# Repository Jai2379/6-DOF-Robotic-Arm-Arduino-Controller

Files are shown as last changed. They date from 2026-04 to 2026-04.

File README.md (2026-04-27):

# 6-DOF Robotic Arm — Arduino Controller

A fully articulated 6-degree-of-freedom robotic arm designed from scratch in SolidWorks and driven by an Arduino-based servo control system. The mechanical design mirrors real industrial robotics architectures — parallel linkages, modular joints, and a kinematic chain built for precision.

---

## Overview

Six degrees of freedom — the same mobility as a human arm. This project spans the full engineering pipeline: mechanical design in SolidWorks, kinematic modeling, and real-time servo control via Arduino. The arm features a parallel-linkage shoulder, articulated elbow, 2-axis wrist, and a mechanical gripper, all coordinated through a custom motion interpolation engine.

### Joint Architecture

```
                        ┌─── J3: Wrist Pitch
                        │    ┌─── J4: Wrist Roll
                        │    │    ┌─── J5: Gripper
    ┌───────────────────┤    │    │
    │   Upper Arm       └────┴────┴──── 🦾 End Effector
    │
    ├─── J2: Elbow
    │
    │   Lower Arm
    │   (Parallel Linkage)
    │
    ├─── J1: Shoulder
    │
    └─── J0: Base Rotation
         ═══════════════
         Circular Platform
```

| Joint | Function | Servo | Range | Home | Notes |
|---|---|---|---|---|---|
| J0 | Base Rotation | MG996R | 0°–180° | 90° | Horizontal yaw on circular platform |
| J1 | Shoulder | MG996R | 15°–165° | 90° | Parallel-linkage lower arm; limits prevent base collision |
| J2 | Elbow | MG996R | 0°–180° | 90° | Upper arm articulation |
| J3 | Wrist Pitch | MG90S | 0°–180° | 90° | End-effector tilt |
| J4 | Wrist Roll | MG90S | 0°–180° | 90° | End-effector rotation |
| J5 | Gripper | MG90S | 10°–73° | 10° | Claw open (10°) / closed (73°) |

---

## Features

- **Coordinated Joint Motion** — All 6 joints interpolate proportionally toward their targets simultaneously, producing smooth, natural arm trajectories instead of jerky sequential moves
- **Mechanical Joint Limits** — Software-enforced angle constraints match the physical range of each joint in the SolidWorks assembly, preventing self-collision and servo damage
- **Serial Command Interface** — Full real-time control over 115200 baud serial. Move individual joints, trigger preset sequences, or adjust speed on the fly
- **Preset Sequences** — Built-in pick-and-place demo and wave gesture that chain coordinated multi-joint movements
- **Adjustable Speed** — Step delay configurable from 1ms (fast) to 100ms (slow) per degree of travel
- **Modular Design** — Joint configuration is table-driven (`JointConfig` struct), making it trivial to adjust limits, pins, or home positions without touching motion logic

---

## Hardware Requirements

### Components

| Component | Qty | Purpose |
|---|-----|---|
| Arduino Mega 2560 | 1 | Controller (Uno works but Mega recommended for pin count) |
| MG996R Servo | 3 | Base, Shoulder, Elbow (high-torque joints) |
| MG90S Servo | 3 | Wrist Pitch, Wrist Roll, Gripper (lighter joints) |
| 6V 5A DC Power Supply | 1 | Dedicated servo power — **do not use Arduino 5V** |
| Breadboard / PCB | 1 | Power distribution and signal routing |
| Jumper Wires | ~20 | Signal + power connections |

### Wiring Diagram

```
                    ┌──────────────────────┐
                    │   Arduino Mega 2560  │
                    │                      │
   Servo J0 ◄──────┤ Pin 2          GND ──┼──── Common GND ────┐
   Servo J1 ◄──────┤ Pin 3                │                    │
   Servo J2 ◄──────┤ Pin 4                │                    │
   Servo J3 ◄──────┤ Pin 5                │      ┌─────────┐   │
   Servo J4 ◄──────┤ Pin 6                │      │  6V 5A  │   │
   Servo J5 ◄──────┤ Pin 7                │      │  PSU    │   │
                    │                      │      │         │   │
                    └──────────────────────┘      │ V+ ─────┼───┼──► Servo V+
                                                  │ GND ────┼───┘
                                                  └─────────┘
```

> ⚠️ **Critical**: Servo motors draw significant current under load (up to 2.5A stall per MG996R). Always use a dedicated external power supply. Powering servos from the Arduino's 5V rail will cause brownouts, erratic behavior, and potential board damage.

---

## Installation

### 1. Clone the Repository

```bash
git clone https://github.com/Jai2379/6-DOF-Robotic-Arm-Arduino-Controller.git
cd 6-DOF-Robotic-Arm
```

### 2. Open in Arduino IDE

- Open `robotic_arm.ino` in Arduino IDE (1.8+ or 2.0+)
- Select board: **Arduino Mega 2560** (or your board)
- Select the correct COM port

### 3. Upload

- Verify/compile: `Ctrl+R`
- Upload: `Ctrl+U`
- Open Serial Monitor: `Ctrl+Shift+M` → Set baud to **115200**

---

## Usage

### Serial Commands

All commands are sent via Serial Monitor at **115200 baud**. Commands are case-insensitive.

| Command | Action | Example |
|---|---|---|
| `Jn:angle` | Move joint `n` to `angle` degrees | `J0:45` — rotate base to 45° |
| `HOME` | All joints return to home position | — |
| `PARK` | Fold arm into compact storage pose | — |
| `PICK` | Run pick-and-place demo sequence | — |
| `WAVE` | Friendly wave gesture | — |
| `GRIP:angle` | Set gripper angle (shortcut for J5) | `GRIP:73` — close gripper |
| `SPEED:ms` | Set interpolation step delay (1–100) | `SPEED:8` — fast movement |
| `POS` | Print all current joint positions | — |
| `HELP` | Display command reference | — |

### Example Session

```
═══════════════════════════════════════
  6-DOF Robotic Arm Controller v1.0
  Joints: Base | Shoulder | Elbow
          Wrist Pitch | Roll | Gripper
═══════════════════════════════════════
  ✓ J0 [Base] attached to pin 2 @ 90°
  ✓ J1 [Shoulder] attached to pin 3 @ 90°
  ✓ J2 [Elbow] attached to pin 4 @ 90°
  ✓ J3 [Wrist Pitch] attached to pin 5 @ 90°
  ✓ J4 [Wrist Roll] attached to pin 6 @ 90°
  ✓ J5 [Gripper] attached to pin 7 @ 10°

> J0:45
[MOVE] Base -> 45°

> GRIP:73
[MOVE] Gripper -> 73°

> POS
─── Current Joint Positions ───
  J0 [Base]: 45°  (0–180°)
  J1 [Shoulder]: 90°  (15–165°)
  J2 [Elbow]: 90°  (0–180°)
  J3 [Wrist Pitch]: 90°  (0–180°)
  J4 [Wrist Roll]: 90°  (0–180°)
  J5 [Gripper]: 73°  (10–73°)
───────────────────────────────

> PICK
[SEQ] Starting PICK sequence...
  -> Pre-pick position
  -> Reaching...
  -> Gripping
  -> Lifting
  -> Rotating to drop zone
  -> Releasing
[INFO] Moving to HOME position...
[INFO] HOME reached.
[SEQ] PICK sequence complete.
```

---

## Project Structure

```
6-DOF-Robotic-Arm/
├── robotic_arm.ino       # Main Arduino sketch — all control logic
├── README.md             # This file
└── solidworks/           # (Optional) SolidWorks assembly files
    ├── full_assembly.SLDASM
    ├── base.SLDPRT
    ├── lower_arm.SLDPRT
    ├── upper_arm.SLDPRT
    ├── wrist.SLDPRT
    └── gripper.SLDPRT
```

---

## How It Works

### Motion Interpolation

The arm doesn't move joints one at a time — it coordinates all 6 simultaneously. The `moveAllJoints()` function finds the joint with the largest angular travel and uses it as the reference. All other joints are linearly interpolated over the same number of steps:

```cpp
for (int step = 1; step <= maxDelta; step++) {
    for (uint8_t i = 0; i < NUM_JOINTS; i++) {
        int pos = startAngle[i] + (delta[i] * step) / maxDelta;
        servos[i].write(pos);
    }
    delay(stepDelayMs);
}
```

This produces smooth, coordinated motion where all joints arrive at their targets at the same time — regardless of how far each one needs to travel.

### Safety: Joint Limits

Every angle command is clamped to the mechanical limits defined in the `JointConfig` table before being sent to the servo. The shoulder joint (J1) is intentionally constrained to 15°–165° to prevent the parallel-linkage arm from colliding with the base platform — a constraint derived directly from the SolidWorks interference analysis.

---

## Roadmap

- [x] SolidWorks mechanical design — full 6-DOF assembly
- [x] Arduino servo control with smooth interpolation
- [x] Serial command interface
- [x] Preset motion sequences (PICK, WAVE)
- [ ] Inverse kinematics solver — move to XYZ coordinates instead of joint angles
- [ ] Joystick / gamepad input for real-time manual control
- [ ] Sensor integration — force-sensitive gripper feedback
- [ ] ROS integration for advanced path planning
- [ ] 3D-printed enclosures for servo mounts and wiring

---

## Tech Stack

| Layer | Technology |
|---|---|
| Mechanical Design | SolidWorks 2024 |
| Microcontroller | Arduino Mega 2560 |
| Language | C++ (Arduino framework) |
| Actuators | MG996R / MG90S Servo Motors |
| Communication | Serial (UART) @ 115200 baud |

---

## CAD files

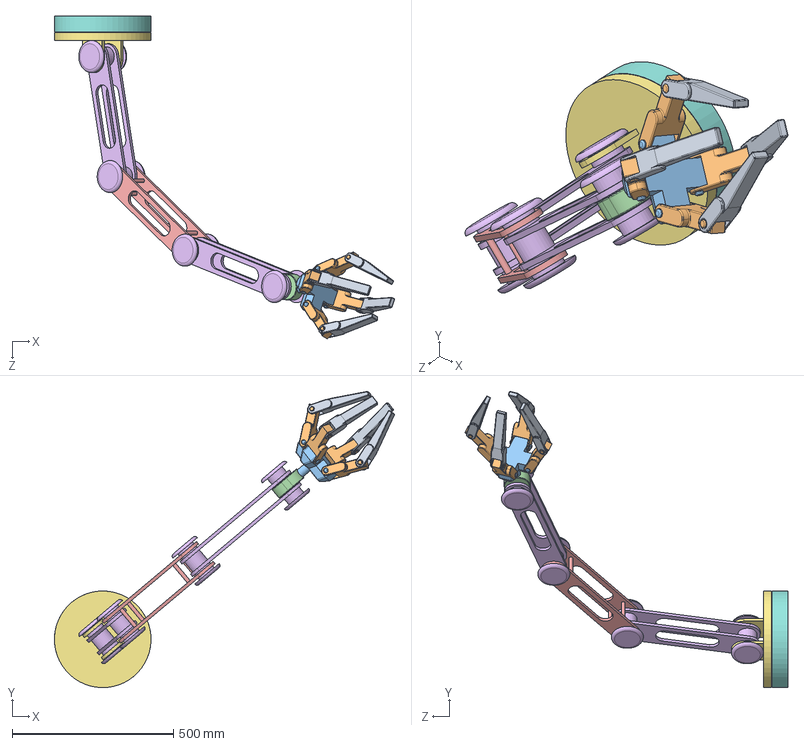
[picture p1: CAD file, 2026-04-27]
Full scale assembly.SLDASM
1056.1 x 919.6 x 1002.7 mm
Base (part 1)]
Rotational Base (Part 2)
Arm Link (Part3) x 2
Arm Link 2 (Part 4)
Gripper Joint (Part 8)
Gripper Base (Part 5)
Gripper Link (Part 6) x 4
Gripper Finger (Part 7) x 4

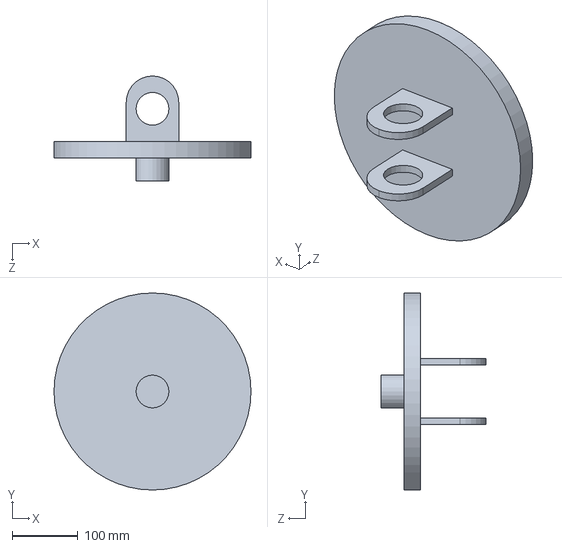
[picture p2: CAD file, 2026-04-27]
Rotational Base (Part 2).SLDPRT
300.0 x 300.0 x 160.0 mm

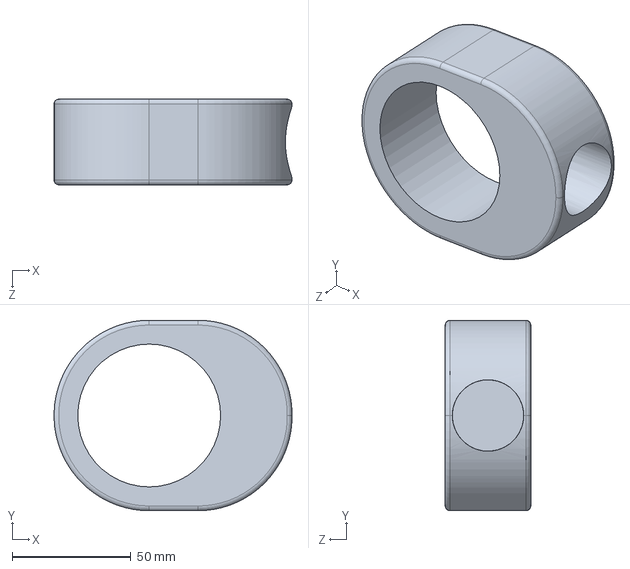
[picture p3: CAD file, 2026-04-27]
Gripper Joint (Part 8).SLDPRT
100.0 x 80.0 x 36.0 mm

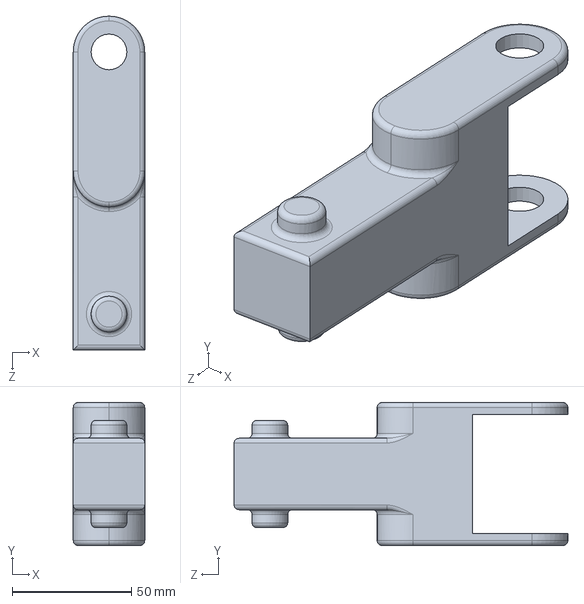
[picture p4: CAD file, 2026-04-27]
Gripper Link (Part 6).SLDPRT
30.0 x 60.0 x 140.0 mm

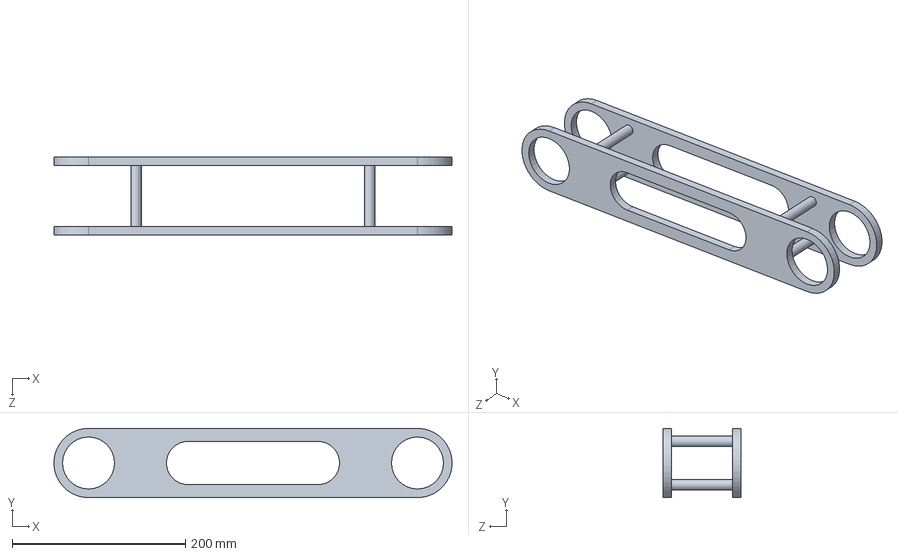
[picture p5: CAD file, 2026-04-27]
Arm Link 2 (Part 4).SLDPRT
459.7 x 80.0 x 90.0 mm

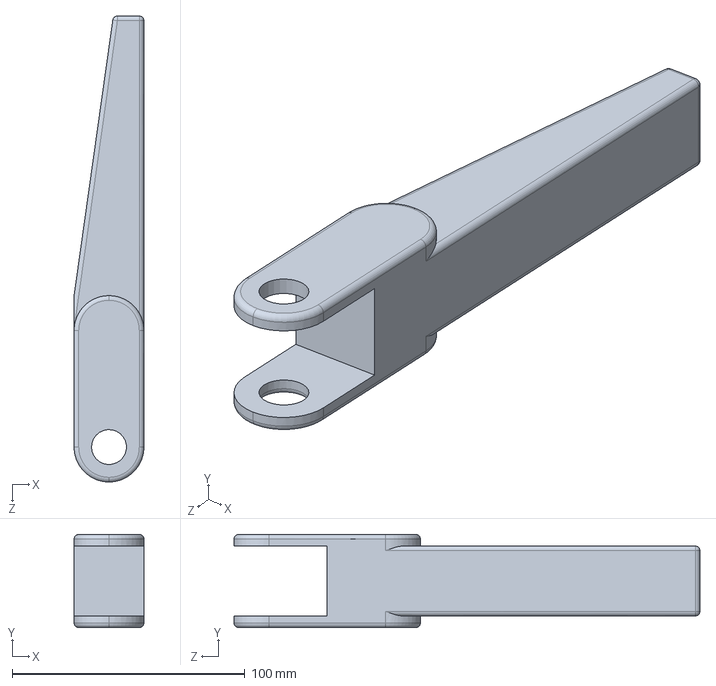
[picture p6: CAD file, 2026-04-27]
Gripper Finger (Part 7).SLDPRT
30.0 x 40.0 x 200.0 mm

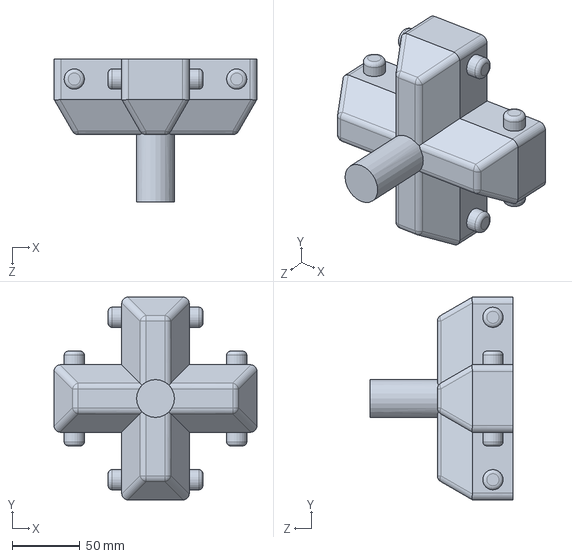
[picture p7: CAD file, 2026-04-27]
Gripper Base (Part 5).SLDPRT
150.0 x 150.0 x 106.0 mm

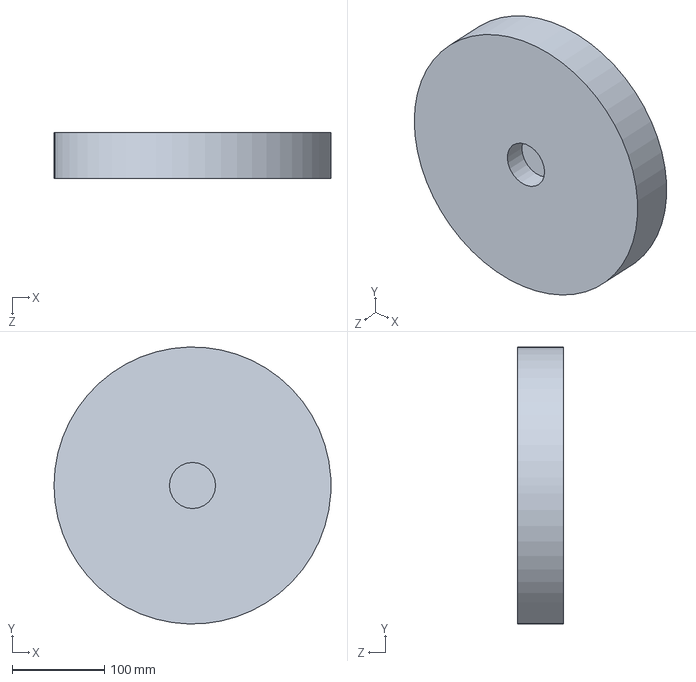
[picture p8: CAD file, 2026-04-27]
Base (part 1)].SLDPRT
300.0 x 299.9 x 50.0 mm

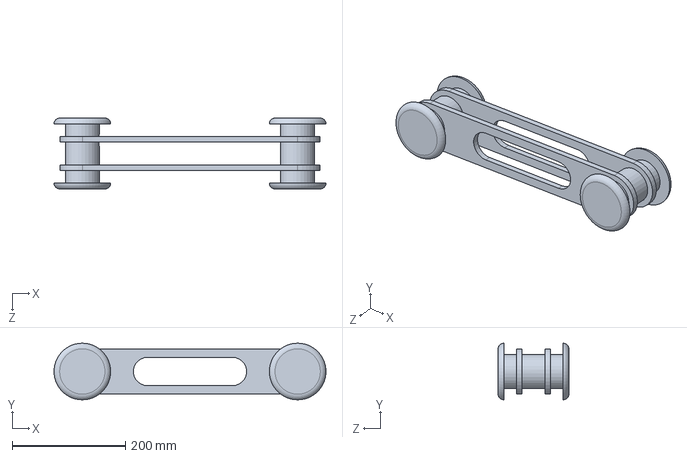
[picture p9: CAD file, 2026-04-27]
Arm Link (Part3).SLDPRT
480.0 x 100.0 x 125.0 mm

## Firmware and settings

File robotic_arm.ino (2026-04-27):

/*
 * ═══════════════════════════════════════════════════════════════
 *  6-DOF Robotic Arm Controller
 *  Designed for: SolidWorks 6-DOF Articulated Arm w/ Parallel Linkage
 * ═══════════════════════════════════════════════════════════════
 *
 *  Joint Map (matching SolidWorks assembly):
 *
 *    Joint 0 — BASE ROTATION    (Servo on circular platform)
 *              Rotates entire arm in horizontal plane (yaw)
 *              Range: 0°–180°  |  Home: 90°
 *
 *    Joint 1 — SHOULDER         (Servo at base-to-lower-arm pivot)
 *              Tilts the lower parallel-linkage arm segment
 *              Range: 15°–165° |  Home: 90°
 *
 *    Joint 2 — ELBOW            (Servo at lower-arm-to-upper-arm pivot)
 *              Bends the upper arm segment relative to lower
 *              Range: 0°–180°  |  Home: 90°
 *
 *    Joint 3 — WRIST PITCH      (Servo at upper-arm-to-wrist pivot)
 *              Tilts the end-effector up/down
 *              Range: 0°–180°  |  Home: 90°
 *
 *    Joint 4 — WRIST ROLL       (Servo rotating the gripper mount)
 *              Rotates end-effector around its own axis
 *              Range: 0°–180°  |  Home: 90°
 *
 *    Joint 5 — GRIPPER          (Servo driving the claw mechanism)
 *              Opens and closes the claw/gripper
 *              Range: 10°–73°  |  Home: 10° (open)
 *
 *  Hardware:
 *    - 6x MG996R or equivalent servo motors (or MG90S for wrist/gripper)
 *    - Arduino Mega 2560 (recommended) or Uno
 *    - External 6V 5A power supply for servos (do NOT power from Arduino 5V)
 *    - Common GND between Arduino and servo PSU
 *
 *  Serial Commands (115200 baud):
 *    Jn:angle     — Move joint n to angle    (e.g. "J0:90")
 *    HOME         — Move all joints to home position
 *    PARK         — Move to folded park position
 *    PICK         — Execute pick-up demo sequence
 *    WAVE         — Friendly wave gesture
 *    GRIP:angle   — Set gripper (shortcut for J5)
 *    SPEED:ms     — Set step delay in ms (default 15)
 *    POS          — Print current joint positions
 *    HELP         — Print command list
 *
 * ═══════════════════════════════════════════════════════════════
 */

#include <Servo.h>

// ─── PIN CONFIGURATION ────────────────────────────────────────
// Use PWM-capable pins. On Mega: 2-13, 44-46. On Uno: 3,5,6,9,10,11.
#define PIN_BASE          2    // Joint 0 — Base rotation
#define PIN_SHOULDER      3    // Joint 1 — Shoulder
#define PIN_ELBOW         4    // Joint 2 — Elbow
#define PIN_WRIST_PITCH   5    // Joint 3 — Wrist pitch
#define PIN_WRIST_ROLL    6    // Joint 4 — Wrist roll
#define PIN_GRIPPER       7    // Joint 5 — Gripper

#define NUM_JOINTS        6

// ─── JOINT LIMITS (degrees) ──────────────────────────────────
// Based on mechanical constraints of the SolidWorks assembly.
// The parallel-linkage shoulder has tighter limits to avoid
// self-collision with the base platform.
struct JointConfig {
    const char* name;
    uint8_t pin;
    uint8_t minAngle;
    uint8_t maxAngle;
    uint8_t homeAngle;
};

const JointConfig JOINTS[NUM_JOINTS] = {
    { "Base",         PIN_BASE,         0,  180,  90 },   // J0
    { "Shoulder",     PIN_SHOULDER,    15,  165,  90 },   // J1
    { "Elbow",        PIN_ELBOW,        0,  180,  90 },   // J2
    { "Wrist Pitch",  PIN_WRIST_PITCH,  0,  180,  90 },   // J3
    { "Wrist Roll",   PIN_WRIST_ROLL,   0,  180,  90 },   // J4
    { "Gripper",      PIN_GRIPPER,     10,   73,  10 },   // J5
};

// ─── GLOBALS ──────────────────────────────────────────────────
Servo servos[NUM_JOINTS];
uint8_t currentAngle[NUM_JOINTS];   // Tracks current position of each joint
uint8_t targetAngle[NUM_JOINTS];    // Target position for interpolated moves
unsigned int stepDelayMs = 15;      // ms between each 1° step (controls speed)

// ─── UTILITY: Clamp angle to joint limits ─────────────────────
uint8_t clampAngle(uint8_t joint, int angle) {
    if (angle < JOINTS[joint].minAngle) return JOINTS[joint].minAngle;
    if (angle > JOINTS[joint].maxAngle) return JOINTS[joint].maxAngle;
    return (uint8_t)angle;
}

// ─── MOVE: Single joint smooth interpolation ──────────────────
// Moves one joint from current position to target, 1° at a time.
void moveJoint(uint8_t joint, uint8_t target) {
    if (joint >= NUM_JOINTS) return;
    target = clampAngle(joint, target);

    int current = currentAngle[joint];
    int step = (target > current) ? 1 : -1;

    while (current != target) {
        current += step;
        servos[joint].write(current);
        delay(stepDelayMs);
    }
    currentAngle[joint] = target;
}

// ─── MOVE: All joints simultaneously (coordinated motion) ─────
// Interpolates all joints toward their targets at roughly the
// same rate so the arm traces a smoother path in joint-space.
void moveAllJoints(uint8_t targets[NUM_JOINTS]) {
    // Clamp all targets
    for (uint8_t i = 0; i < NUM_JOINTS; i++) {
        targets[i] = clampAngle(i, targets[i]);
    }

    // Find the joint with the largest travel distance
    int maxDelta = 0;
    for (uint8_t i = 0; i < NUM_JOINTS; i++) {
        int delta = abs((int)targets[i] - (int)currentAngle[i]);
        if (delta > maxDelta) maxDelta = delta;
    }

    if (maxDelta == 0) return; // Already at target

    // Step all joints proportionally
    for (int step = 1; step <= maxDelta; step++) {
        for (uint8_t i = 0; i < NUM_JOINTS; i++) {
            int delta = (int)targets[i] - (int)currentAngle[i];
            // Linear interpolation: position = start + (delta * step / maxDelta)
            int pos = (int)currentAngle[i] + (delta * step) / maxDelta;
            // Avoid redundant writes — only if the rounded position changed
            servos[i].write(pos);
        }
        delay(stepDelayMs);
    }

    // Finalize positions
    for (uint8_t i = 0; i < NUM_JOINTS; i++) {
        currentAngle[i] = targets[i];
        servos[i].write(targets[i]);
    }
}

// ─── PRESET: Home position ────────────────────────────────────
// Arm stands upright, centered, gripper open.
void goHome() {
    Serial.println(F("[INFO] Moving to HOME position..."));
    uint8_t home[NUM_JOINTS];
    for (uint8_t i = 0; i < NUM_JOINTS; i++) {
        home[i] = JOINTS[i].homeAngle;
    }
    moveAllJoints(home);
    Serial.println(F("[INFO] HOME reached."));
}

// ─── PRESET: Park (folded compact position) ──────────────────
// Arm folds down for storage/transport. Minimizes profile.
void goPark() {
    Serial.println(F("[INFO] Moving to PARK position..."));
    uint8_t park[NUM_JOINTS] = {
        90,   // Base centered
        150,  // Shoulder folded down toward base
        30,   // Elbow tucked in
        90,   // Wrist neutral
        90,   // Roll neutral
        10    // Gripper open
    };
    moveAllJoints(park);
    Serial.println(F("[INFO] PARK reached."));
}

// ─── SEQUENCE: Pick-up demo ──────────────────────────────────
// Demonstrates reaching forward, gripping, lifting, and returning.
void pickSequence() {
    Serial.println(F("[SEQ] Starting PICK sequence..."));

    // 1. Move to pre-pick position (arm extended forward, low)
    uint8_t prePick[NUM_JOINTS] = { 90, 60, 120, 130, 90, 10 };
    Serial.println(F("  -> Pre-pick position"));
    moveAllJoints(prePick);
    delay(300);

    // 2. Lower to object (shoulder drops, wrist adjusts)
    uint8_t reach[NUM_JOINTS] = { 90, 45, 135, 140, 90, 10 };
    Serial.println(F("  -> Reaching..."));
    moveAllJoints(reach);
    delay(300);

    // 3. Close gripper
    Serial.println(F("  -> Gripping"));
    moveJoint(5, 73);  // Gripper closed
    delay(500);

    // 4. Lift object (shoulder raises, elbow straightens)
    uint8_t lift[NUM_JOINTS] = { 90, 90, 90, 90, 90, 73 };
    Serial.println(F("  -> Lifting"));
    moveAllJoints(lift);
    delay(300);

    // 5. Rotate to drop position
    uint8_t drop[NUM_JOINTS] = { 45, 90, 90, 90, 90, 73 };
    Serial.println(F("  -> Rotating to drop zone"));
    moveAllJoints(drop);
    delay(300);

    // 6. Release
    Serial.println(F("  -> Releasing"));
    moveJoint(5, 10);  // Gripper open
    delay(300);

    // 7. Return home
    goHome();
    Serial.println(F("[SEQ] PICK sequence complete."));
}

// ─── SEQUENCE: Wave gesture ──────────────────────────────────
void waveSequence() {
    Serial.println(F("[SEQ] Waving..."));

    // Raise arm
    uint8_t raised[NUM_JOINTS] = { 90, 90, 45, 90, 90, 73 };
    moveAllJoints(raised);
    delay(200);

    // Wave the wrist back and forth 3 times
    for (int i = 0; i < 3; i++) {
        moveJoint(3, 45);
        moveJoint(3, 135);
    }
    moveJoint(3, 90);
    delay(200);

    goHome();
    Serial.println(F("[SEQ] Wave complete."));
}

// ─── PRINT: Current joint positions ──────────────────────────
void printPositions() {
    Serial.println(F("─── Current Joint Positions ───"));
    for (uint8_t i = 0; i < NUM_JOINTS; i++) {
        Serial.print(F("  J"));
        Serial.print(i);
        Serial.print(F(" ["));
        Serial.print(JOINTS[i].name);
        Serial.print(F("]: "));
        Serial.print(currentAngle[i]);
        Serial.print(F("°  ("));
        Serial.print(JOINTS[i].minAngle);
        Serial.print(F("–"));
        Serial.print(JOINTS[i].maxAngle);
        Serial.println(F("°)"));
    }
    Serial.println(F("───────────────────────────────"));
}

// ─── PRINT: Help / command reference ─────────────────────────
void printHelp() {
    Serial.println(F(""));
    Serial.println(F("╔═══════════════════════════════════════╗"));
    Serial.println(F("║   6-DOF Robotic Arm — Command List    ║"));
    Serial.println(F("╠═══════════════════════════════════════╣"));
    Serial.println(F("║ Jn:angle  Move joint n to angle       ║"));
    Serial.println(F("║           e.g. J0:90, J5:73           ║"));
    Serial.println(F("║ HOME      All joints to home          ║"));
    Serial.println(F("║ PARK      Fold arm for storage        ║"));
    Serial.println(F("║ PICK      Pick-up demo sequence       ║"));
    Serial.println(F("║ WAVE      Wave gesture                ║"));
    Serial.println(F("║ GRIP:n    Set gripper angle            ║"));
    Serial.println(F("║ SPEED:n   Set step delay (ms)         ║"));
    Serial.println(F("║ POS       Print current positions     ║"));
    Serial.println(F("║ HELP      Show this message           ║"));
    Serial.println(F("╚═══════════════════════════════════════╝"));
    Serial.println(F(""));
}

// ─── SERIAL COMMAND PARSER ────────────────────────────────────
void parseCommand(String cmd) {
    cmd.trim();
    cmd.toUpperCase();

    if (cmd == "HOME") {
        goHome();
    }
    else if (cmd == "PARK") {
        goPark();
    }
    else if (cmd == "PICK") {
        pickSequence();
    }
    else if (cmd == "WAVE") {
        waveSequence();
    }
    else if (cmd == "POS") {
        printPositions();
    }
    else if (cmd == "HELP") {
        printHelp();
    }
    else if (cmd.startsWith("SPEED:")) {
        int val = cmd.substring(6).toInt();
        if (val >= 1 && val <= 100) {
            stepDelayMs = val;
            Serial.print(F("[INFO] Step delay set to "));
            Serial.print(stepDelayMs);
            Serial.println(F(" ms"));
        } else {
            Serial.println(F("[ERR] Speed must be 1–100 ms"));
        }
    }
    else if (cmd.startsWith("GRIP:")) {
        int angle = cmd.substring(5).toInt();
        Serial.print(F("[MOVE] Gripper -> "));
        Serial.println(angle);
        moveJoint(5, angle);
    }
    else if (cmd.startsWith("J") && cmd.indexOf(':') > 0) {
        // Parse "Jn:angle"
        int colonIdx = cmd.indexOf(':');
        int joint = cmd.substring(1, colonIdx).toInt();
        int angle = cmd.substring(colonIdx + 1).toInt();

        if (joint >= 0 && joint < NUM_JOINTS) {
            Serial.print(F("[MOVE] "));
            Serial.print(JOINTS[joint].name);
            Serial.print(F(" -> "));
            Serial.print(clampAngle(joint, angle));
            Serial.println(F("°"));
            moveJoint(joint, angle);
        } else {
            Serial.println(F("[ERR] Invalid joint index (0–5)"));
        }
    }
    else {
        Serial.print(F("[ERR] Unknown command: "));
        Serial.println(cmd);
        Serial.println(F("       Type HELP for command list."));
    }
}

// ═══════════════════════════════════════════════════════════════
//  SETUP
// ═══════════════════════════════════════════════════════════════
void setup() {
    Serial.begin(115200);
    while (!Serial) { ; }  // Wait for serial on boards with native USB

    Serial.println(F(""));
    Serial.println(F("═══════════════════════════════════════"));
    Serial.println(F("  6-DOF Robotic Arm Controller v1.0"));
    Serial.println(F("  Joints: Base | Shoulder | Elbow"));
    Serial.println(F("          Wrist Pitch | Roll | Gripper"));
    Serial.println(F("═══════════════════════════════════════"));

    // Attach all servos and move to home position
    for (uint8_t i = 0; i < NUM_JOINTS; i++) {
        servos[i].attach(JOINTS[i].pin);
        currentAngle[i] = JOINTS[i].homeAngle;
        servos[i].write(currentAngle[i]);
        Serial.print(F("  ✓ J"));
        Serial.print(i);
        Serial.print(F(" ["));
        Serial.print(JOINTS[i].name);
        Serial.print(F("] attached to pin "));
        Serial.print(JOINTS[i].pin);
        Serial.print(F(" @ "));
        Serial.print(currentAngle[i]);
        Serial.println(F("°"));
    }

    Serial.println(F(""));
    Serial.println(F("  All servos initialized at HOME."));
    Serial.println(F("  Type HELP for command list."));
    Serial.println(F("═══════════════════════════════════════"));
    Serial.println(F(""));
}

// ═══════════════════════════════════════════════════════════════
//  MAIN LOOP
// ═══════════════════════════════════════════════════════════════
void loop() {
    if (Serial.available() > 0) {
        String cmd = Serial.readStringUntil('\n');
        parseCommand(cmd);
    }
}
